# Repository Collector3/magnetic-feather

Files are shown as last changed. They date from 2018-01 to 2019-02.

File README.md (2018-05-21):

# Magnetic Feather Case

Designed for [Adafruit's Feather series](https://learn.adafruit.com/adafruit-feather/overview). 
Flexible enough to use from development to deployment.

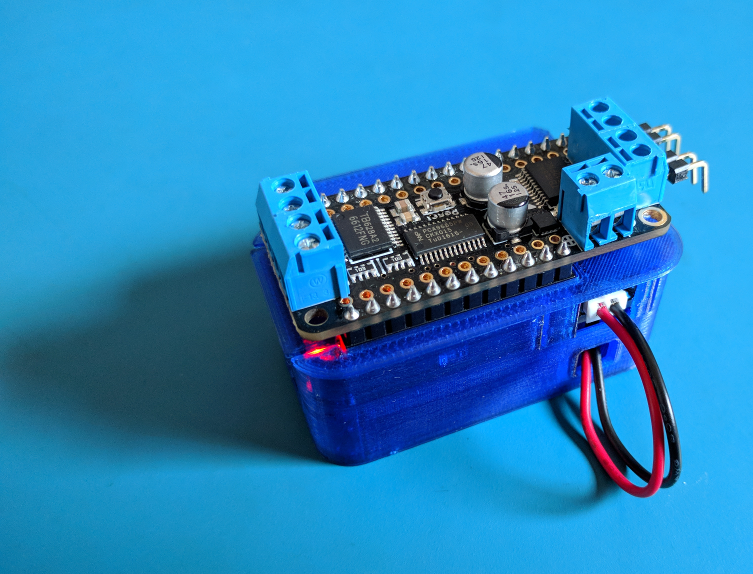
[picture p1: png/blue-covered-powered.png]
Case With Feather Wing Attached


### Features

* Optional compartment for a 350mAh LiPoly battery (with a zip-tie strain relief slot)

* Slot for a rare earth badge magnet (source provided)

* Support for Adafruit's stackable Feather wings

* Cable management and routing slots

* Upside down board support (battery version only)

### Materials Required

#### Feather + Screws

* 1x Adafruit Feather (ESP8266, Bluefruit, ESP32, Adalogger 32u4 were used during prototyping/building)

* 2x M2.5 x 6mm socket head cap screws (source: [Trimcraft Aviation RC](https://www.trimcraftaviationrc.com/index.php?route=product/product&product_id=182))

#### Battery (optional)

* 1x Lithium Ion Polymer Battery - 3.7v 350mAh 552035 - [PKCell 552035, Adafruit](https://www.adafruit.com/product/2750). There are shipping restrictions on lithium polymer batteries, so a local source with the same model/dimensions might be more suitable.

#### Magnet

* 1x Badge Magnet - [Amazon 10-pack](https://www.amazon.com/totalElement-Magnetic-Fastener-Adhesive-10-Pack/dp/B00EHK287M) -- the one [sold by Adafruit is tested as well](https://www.adafruit.com/product/1170)

### Printing

Print these parts:

* 1x - Case (choose between the battery and non-battery version)

* 1x - Cover (choose between the JST access and more enclosed version)

* 1x - Magnet retainer

* 1x - Reset button

* 2x - M2.5 plastic spacers

### Assembly

#### Battery

After printing all three parts, place the battery in first. The battery wiring can be routed through the front of the case, and looped up the side to the Feather's JST header. If desired, add a small zip tie (for a bit of strain relief) on the front of the case.

For the visually inclined, photos are provided below.

#### Badge magnet and retainer

The badge magnet goes into the case with the warning symbols facing up. 

For magnets with a metal-only plate: Insert the magnet retainer with the 1st printed layer facing upward. 

For magnets with a plastic backing: Flip the magnet retainer over so that the last printed layer faces upwards.

Press the retainer through the clips. The retainer should click in and press against the magnet. If there is space between the retainer and magnet, the retainer might need to be flipped over.

#### Feather PCB

Finally, add the Feather PCB into the case, ensuring the board seats into the case's rear notches fully. Carefully press the board down in front. 

Attach a printed spacer to a screw by screwing it on.

Finally, attach the screw to the Feather PCB. The LEDs will be in close proximity to the screw heads, but should not interfere.

#### Reset Button

Attach the button to the lid. It requires a bit of force, so the best way may be to either shave off a bit of filament on the button with a file, or to press it in by tapping the cover onto the button.

### Photos

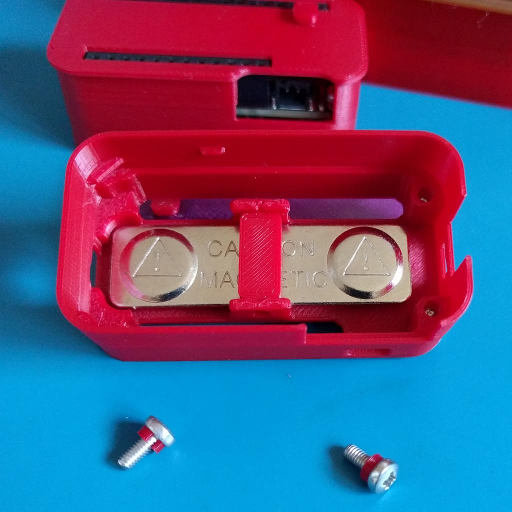
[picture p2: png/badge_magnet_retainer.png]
Badge magnet with printed retainer


The badge magnet is held in by a printed retainer. It is quite strong (this particular one has survived a few hard drops), and should be easy to insert after the badge magnet has been seated in the case. Be sure that it clicks into place fully and that there is little to no movement of the magnet.

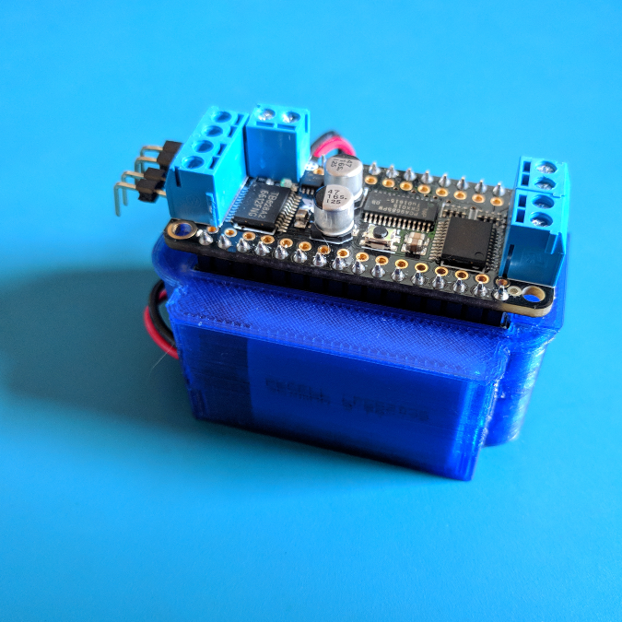
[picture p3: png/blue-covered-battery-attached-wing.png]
Attached Feather Wing with battery


Assembled case with a Feather and Feather wing attached. The battery wiring is routed through the case, past a point where a small zip tie can be used to fix the wires in place.

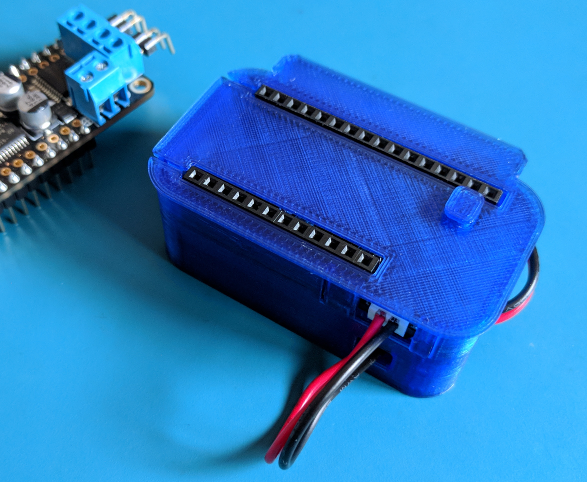
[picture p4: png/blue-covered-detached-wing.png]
Detached Wing


After exiting the bottom of the case, the wiring can be routed back up into the JST header. The slot for the JST connector is spaced (with the cover off) for access with two fingers. With a Wing attached, access is a bit more restricted. For now, the cover (and any attached wings), will need to be removed for access to the JST plug.

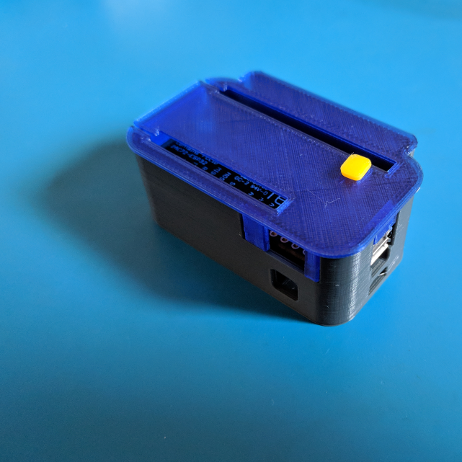
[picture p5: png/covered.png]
Upside down ESP32 Feather


Depending on the Feather/PCB, it may be possible to use a Feather "upside down" for prototyping -- Feathers have different layouts and construction, so inspect the case and Feather's tolerances before trying.

There is no cover for this configuration -- the JST jack is also obstructed.

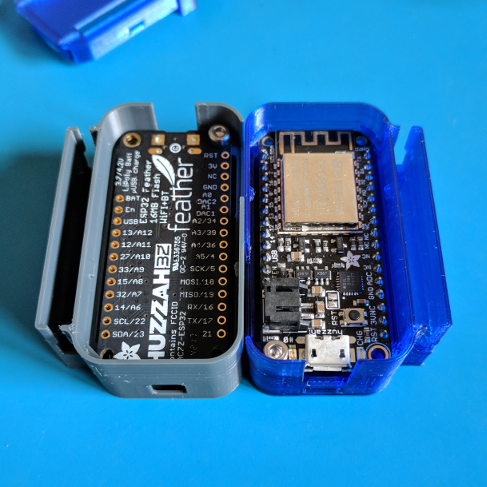
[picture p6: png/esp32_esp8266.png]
ESP32 upside down + ESP8266 side by side


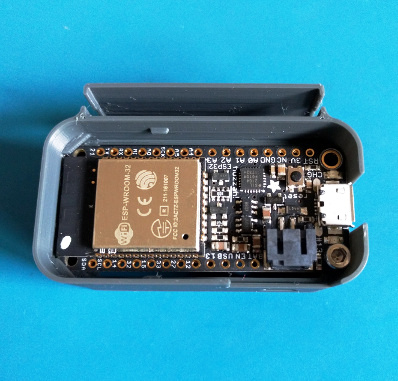
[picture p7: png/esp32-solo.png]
ESP32 without a cover on and one screw


In most configurations, only one hex screw is needed. If the head of the screw gets in the way, try printing the ***M2.5 plastic spacer***, which should provide enough clearance to avoid the LEDs and cover closure.

### Using the Enable Pin To Disconnect Power

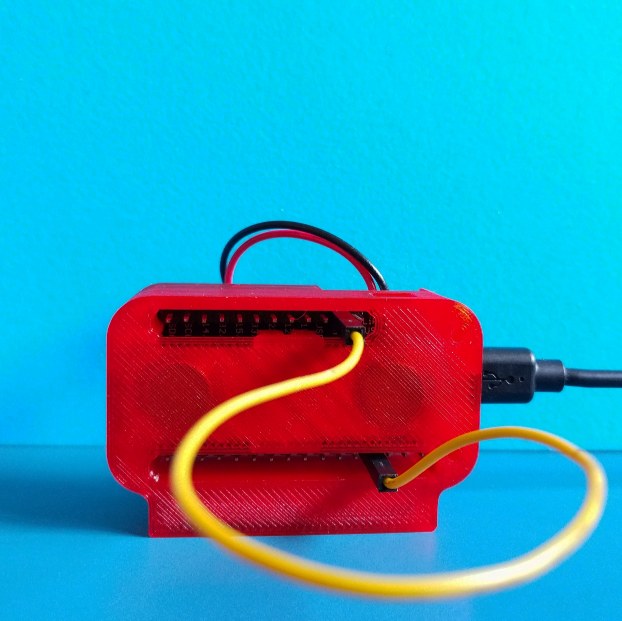
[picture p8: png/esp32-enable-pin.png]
ESP32 Enable Pin Photo


On the ESP32: Nominal consumption with the default program (which scans for SSIDs) is around 130mA (burst). With the enable pin pulled low, quiescent power consumption is around 100μA.

With a full battery, using the enable pin to limit consumption drains a 350 mAh battery in about 100 days (optimistic estimate with an adjustment factor of 0.7).

### Fin

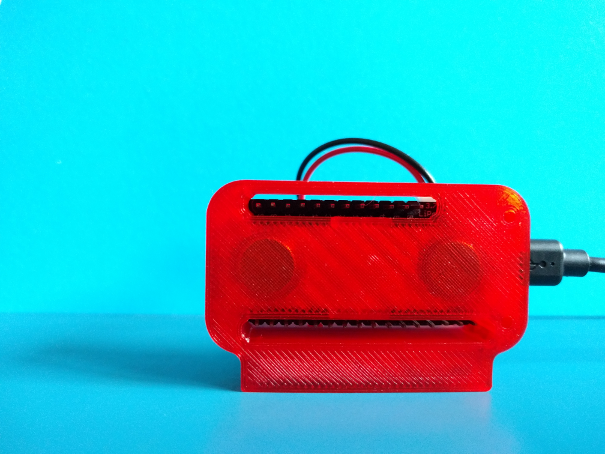
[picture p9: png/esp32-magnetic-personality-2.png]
Final image


More resources:

* [Adafruit's ESP32 Documentation](https://learn.adafruit.com/adafruit-huzzah32-esp32-feather/overview)

* [Adafruit's ESP8266 Documentation](https://learn.adafruit.com/adafruit-feather-huzzah-esp8266/)

* [Adafruit's Feather Series](https://www.adafruit.com/feather/)

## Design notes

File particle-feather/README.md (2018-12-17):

# Particle Feather

A derivitave of the magnetic feather series of cases for the Particle Argon / Xenon (and possibly Boron).

Elsewhere, [Thingiverse](https://www.thingiverse.com/thing:3292215)

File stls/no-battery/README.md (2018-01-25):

# magnetic feather (no battery compartment)

This is a magnetic case with the battery compartment removed. The reset button and magnet retainer are shared with the other parts (look for them in stl/).

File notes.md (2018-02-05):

# Notes

This project is located in other places too.

* [Thingiverse: https://www.thingiverse.com/thing:2749893](https://www.thingiverse.com/thing:2749893)

* [YouMagine: https://www.youmagine.com/designs/magnetic-feather-case](https://www.youmagine.com/designs/magnetic-feather-case)

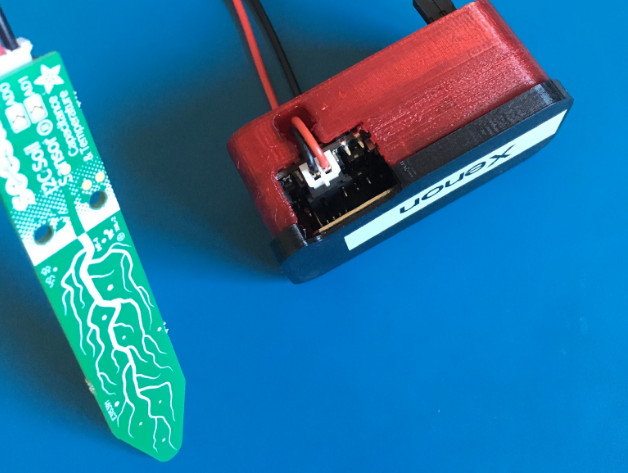
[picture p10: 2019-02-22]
particle-feather/png/feather-ideal-battery-side.png

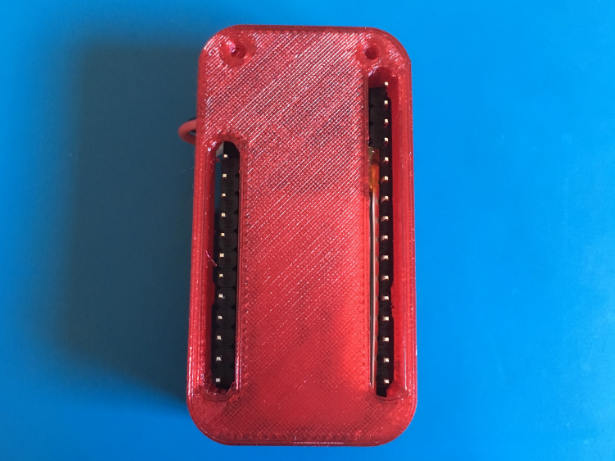
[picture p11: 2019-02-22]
particle-feather/png/feather-ideal-battery-bottom.png

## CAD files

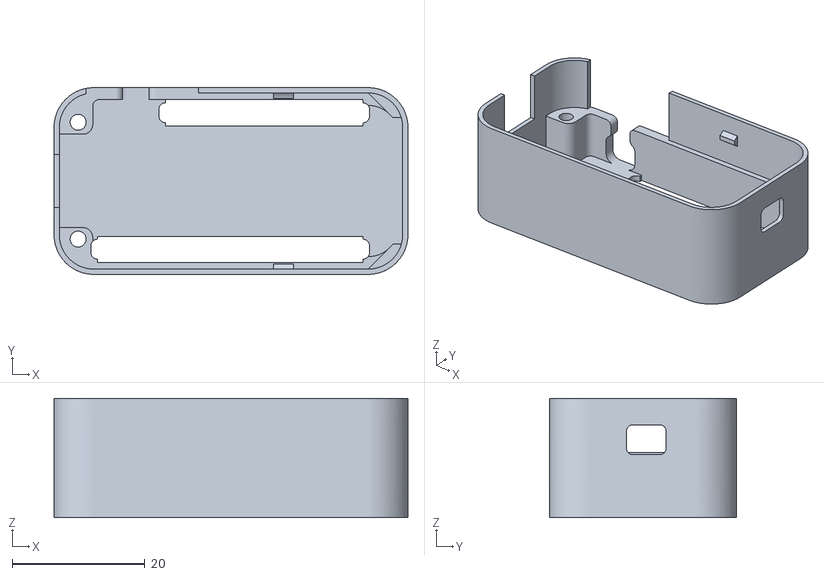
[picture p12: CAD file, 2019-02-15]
particle-feather/Particle-Feather-Ideal-Battery.stl
53.4 x 28.1 x 18.0

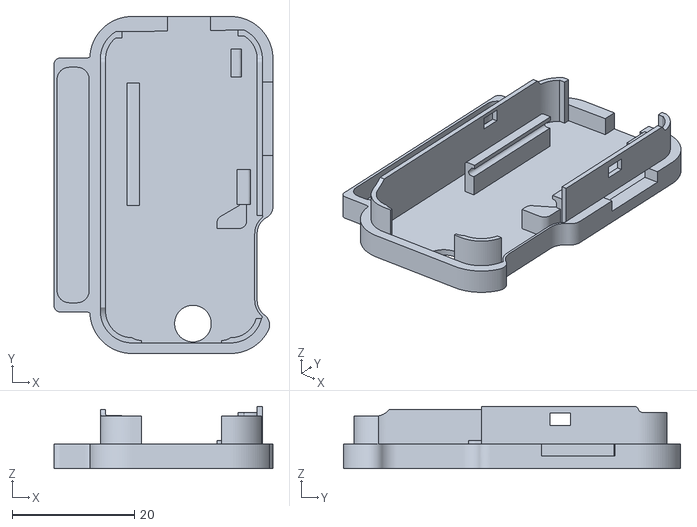
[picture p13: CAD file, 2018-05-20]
stls/camera-module/integrated-cover-camera.stl
35.9 x 55.2 x 10.2

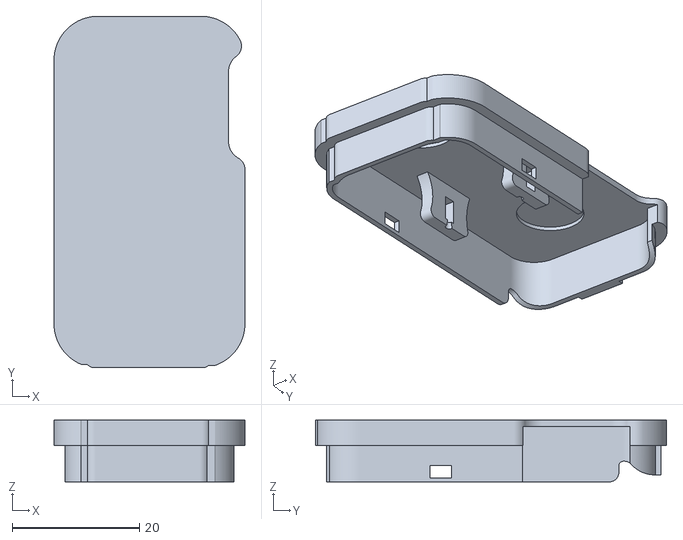
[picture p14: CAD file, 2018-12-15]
stls/feather-magnetic-cover - part.stl
30.0 x 55.2 x 9.70

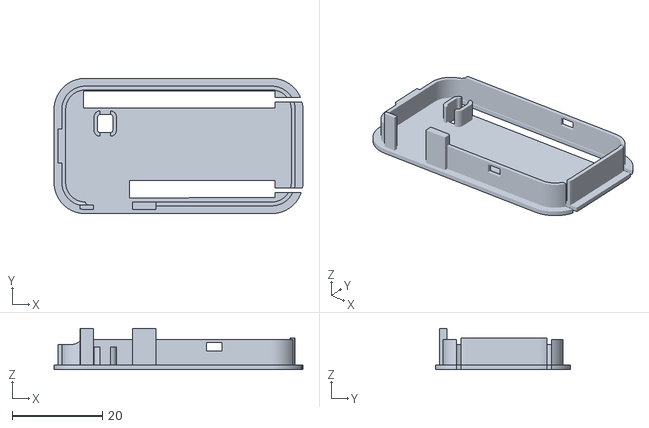
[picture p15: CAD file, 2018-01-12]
stls/no-battery/cover-no-battery.stl
55.2 x 30.0 x 9.20

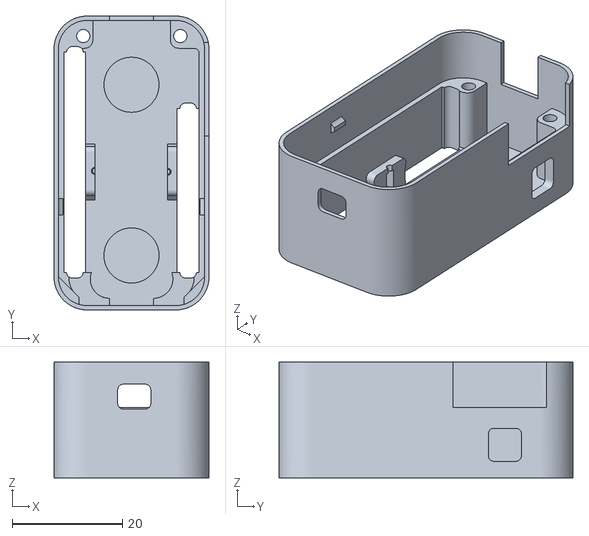
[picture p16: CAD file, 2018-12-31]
particle-feather/Particle-Feather-Base.stl
28.1 x 53.4 x 21.0

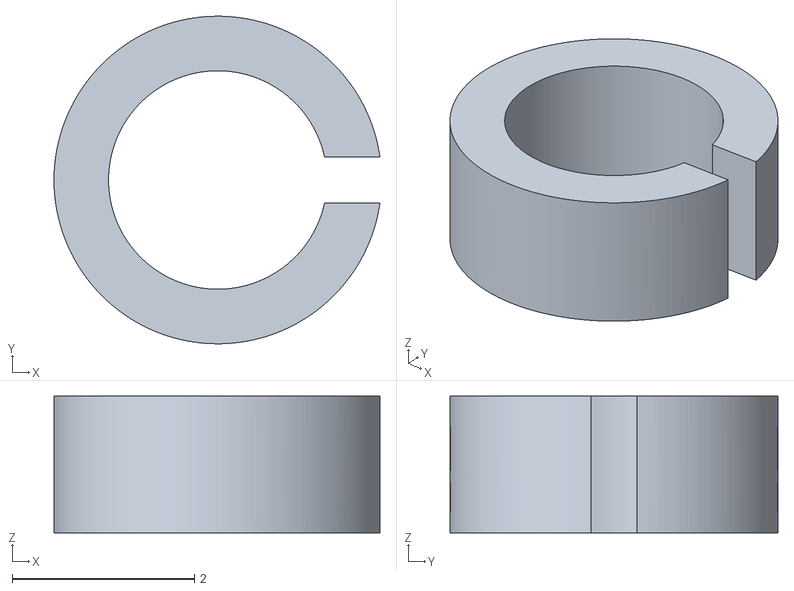
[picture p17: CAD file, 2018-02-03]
stls/feather-m2.5-plastic-spacer.stl
3.58 x 3.60 x 1.50

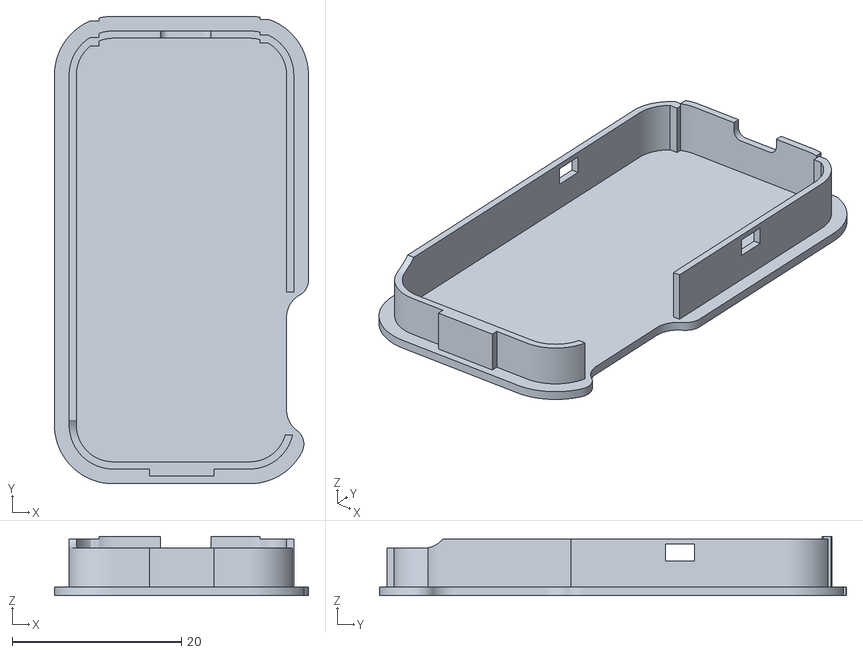
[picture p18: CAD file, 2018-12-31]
particle-feather/Particle-Feather-Top.stl
30.0 x 55.2 x 7.00

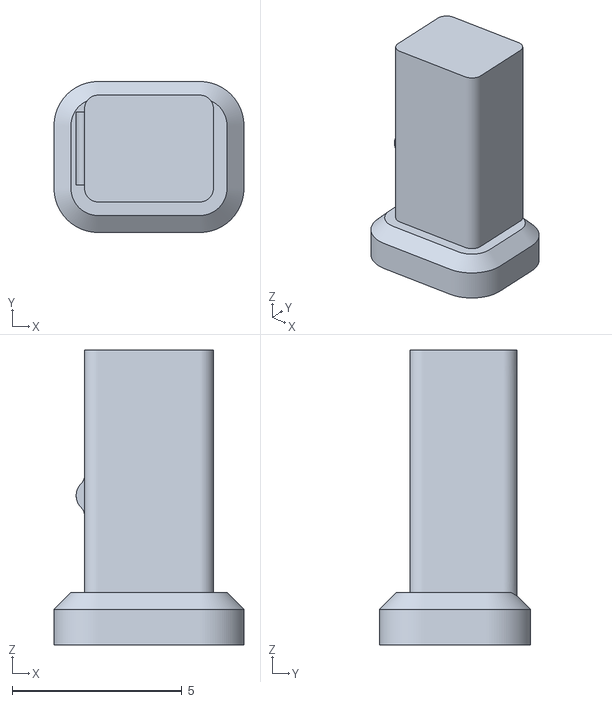
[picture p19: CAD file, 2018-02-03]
stls/reset_button.stl
5.60 x 4.45 x 8.70

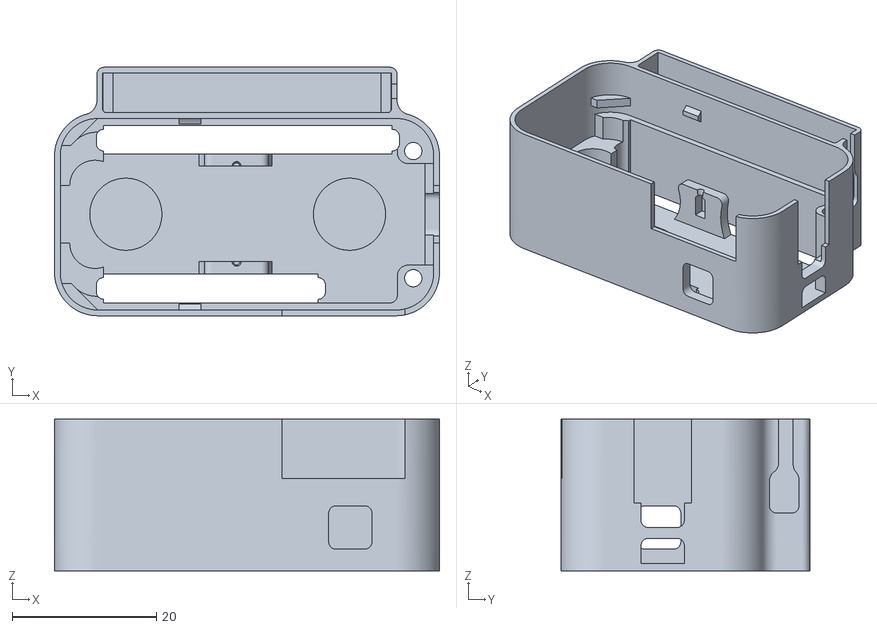
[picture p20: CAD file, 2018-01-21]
stls/case.stl
53.4 x 34.4 x 21.0

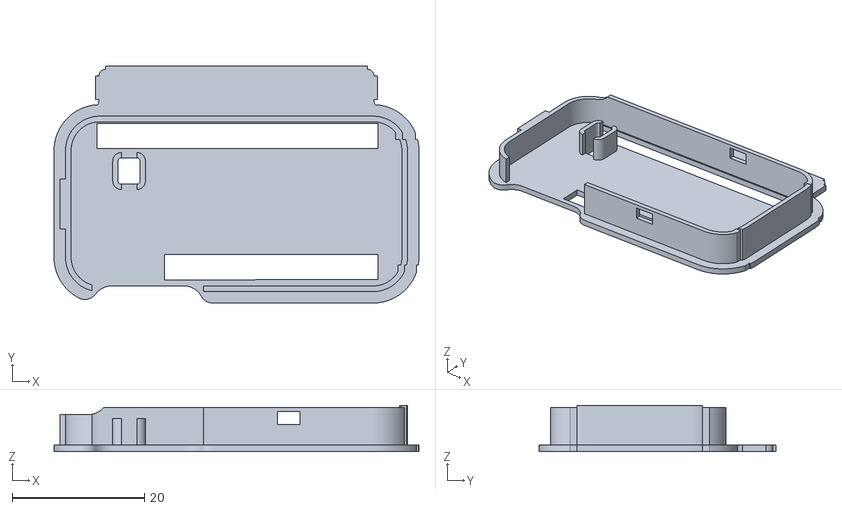
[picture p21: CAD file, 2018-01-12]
stls/cover-jst-access.stl
55.2 x 35.9 x 7.00

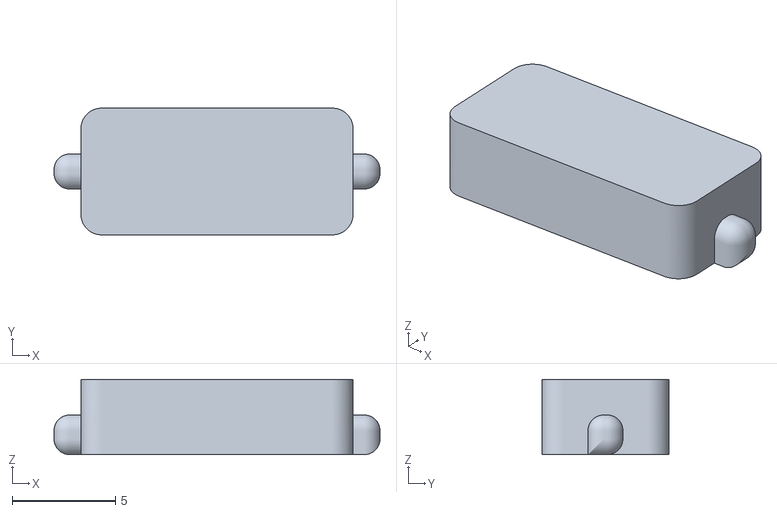
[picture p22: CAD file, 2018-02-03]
particle-feather/magnet-retainer.stl
15.8 x 6.13 x 3.63

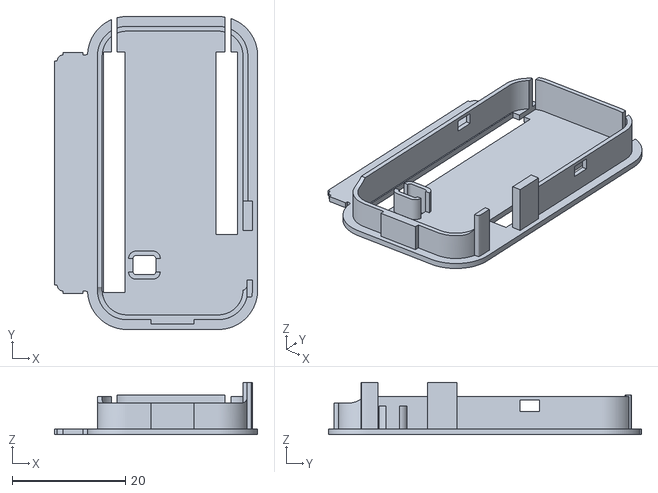
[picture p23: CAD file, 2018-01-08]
stls/cover.stl
35.9 x 55.2 x 9.20

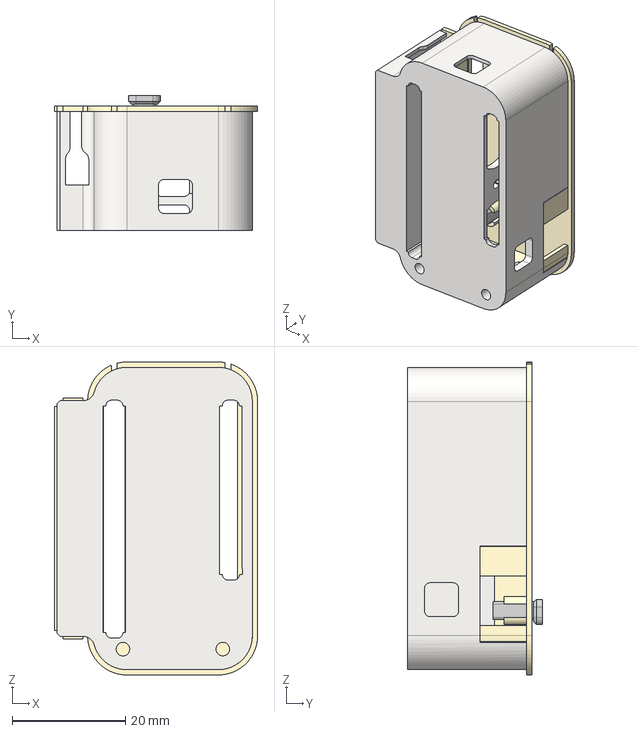
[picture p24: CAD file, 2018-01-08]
stls/esp.stp
35.9 x 23.8 x 55.2 mm

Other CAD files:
particle-feather/Particle-Feather-Top-Magnet.stl
particle-feather/cover-magnet-support.step

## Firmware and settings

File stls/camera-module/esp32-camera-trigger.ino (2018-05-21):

// Sample code for an ESP32 board combined with this camera from Adafruit https://www.adafruit.com/product/3202
//
// This code was cut together (and down) from a combination of:
// RepeatTimer: https://raw.githubusercontent.com/espressif/arduino-esp32/master/libraries/ESP32/examples/Timer/RepeatTimer/RepeatTimer.ino
//  License: Public domain
// CaptivePortal: https://raw.githubusercontent.com/espressif/arduino-esp32/master/libraries/DNSServer/examples/CaptivePortal/CaptivePortal.ino
//  License: LGPL Arduino Port (documentation)
// SimpleWebServer: https://raw.githubusercontent.com/espressif/arduino-esp32/master/libraries/WiFi/examples/SimpleWiFiServer/SimpleWiFiServer.ino
//  License: LGPL Arduino Port (documentation)
// Any other unique bits should also be considered as: LGPL licensed
//
#include <WiFi.h>
#include <DNSServer.h>

#define TRIG_PIN A0
#define BATTERY_V_PIN A13

DNSServer dnsServer;
WiFiServer server(80);

const byte DNS_PORT = 53;
const int timelapseIntervalSeconds = 5;

IPAddress apIpAddr(192, 168, 4, 1);
bool timelapse = false;

const char* ssid     = "CAMERA-CONTROLLER";
const char* password = "";

hw_timer_t * timer = NULL;
volatile SemaphoreHandle_t timerSemaphore;
portMUX_TYPE timerMux = portMUX_INITIALIZER_UNLOCKED;

void IRAM_ATTR onTimer(){
  xSemaphoreGiveFromISR(timerSemaphore, NULL);
  takePhoto();
}

void setup()
{
    Serial.begin(115200);
    
    pinMode(TRIG_PIN, OUTPUT);
    digitalWrite(TRIG_PIN, HIGH);
        
    pinMode(BATTERY_V_PIN, INPUT);
    
    WiFi.mode(WIFI_AP);
    WiFi.softAPConfig(apIpAddr, apIpAddr, IPAddress(255, 255, 255, 0));
    WiFi.softAP(ssid, password);
    
    Serial.println(ssid);
    Serial.println(password);
        
    dnsServer.start(DNS_PORT, "*", apIpAddr);
    server.begin();
    
    timerSemaphore = xSemaphoreCreateBinary();
    timer = timerBegin(0, 80, true);
    timerAttachInterrupt(timer, &onTimer, true);

    timerAlarmWrite(timer, timelapseIntervalSeconds * 1000000, true);
    Serial.println("Entering main loop()");
}

// takePhoto() snaps a picture
// Line is assumed to be HIGH before calling this
void takePhoto() {        
    digitalWrite(TRIG_PIN, LOW);
    delay(50);
    Serial.println("Photo taken.");
}

// takeVideo() toggles video recording
// Line is assumed to be HIGH before calling this
void takeVideo() {
    digitalWrite(TRIG_PIN, LOW);
    delay(800);
    Serial.println("Toggled video recording."); 
}

// getBatteryVoltage() returns the internal battery voltage
// measured by a /2 resistive divider on pin A13 (specific
// to the ESP32 HUZZAH)
float getBatteryVoltage() {
    return (analogRead(BATTERY_V_PIN) * 2);
}

void loop() {
  dnsServer.processNextRequest();
  WiFiClient client = server.available();

  digitalWrite(TRIG_PIN, HIGH);

  if (client) {                             
    Serial.println("Incoming connection.");
    String currentLine = "";
    while (client.connected()) {
      if (client.available()) {
        char c = client.read();
        Serial.write(c);
        if (c == '\n') {
          if (currentLine.length() == 0) {
            client.println("HTTP/1.1 200 OK");
            client.println("Content-type:text/html");
            client.println();

            client.print("My IP is: ");
            client.print("<a href=\"");
            client.print("\"");
            client.print(apIpAddr);
            client.print("/");
            client.print(">");
            client.print(apIpAddr);
            client.print("</a><br><br><br>");
            
            client.print("Battery voltage is: ");
            client.print(getBatteryVoltage());
            client.print(" mV");
            client.print("<br><br><br>");
            client.print("<a href=\"/PHOTO\">TAKE A PHOTO</a><br><br><br>");
            client.print("<a href=\"/VIDEO\">START/STOP VIDEO</a><br><br><br>");
            
            if(timelapse) {
              client.print("Photo timelapse: Started<br><br>");
            } else {
              client.print("Photo timelapse: Stopped<br><br>");
            }
            
            client.print("<a href=\"/TIMELAPSE\">START/STOP PHOTO TIMELAPSE</a><br><br><br>");
                               
            client.println();
            break;
            
          } else {
            currentLine = "";
          }
        } else if (c != '\r') {
          currentLine += c;
        }

        if (currentLine.endsWith("GET /TIMELAPSE")) {
          
          if (!timelapse) {
            
            timelapse = true;
            timerAlarmEnable(timer);
            Serial.print("Timelapse mode enabled");
            
          } else {
            
            timelapse = false;
            
            if (timer) {
              timerEnd(timer);
            }
            
            Serial.print("Timelapse mode disabled");
            
          }
        }
        
        if (currentLine.endsWith("GET /PHOTO")) {
          takePhoto();
        }
        
        if (currentLine.endsWith("GET /VIDEO")) {
          takeVideo();
        }
        
      }
    }
    
    client.stop();
    Serial.println("Connection finished.");
    
  }
}

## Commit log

2018-01-03 case -> board
2018-01-03 More about the enable pin
2018-01-08 Enable pin corrections
2018-01-08 Add license for project
    [case.stl, cover.stl, esp.stp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]
2018-01-08 Rotate all STLs for printability
    [case.stl, cover.stl, reset_button.stl]
2018-01-10 Add a printed part for fixing the magnet in place
    [feather-case-magnet-fixer.stl]
2018-01-10 Move feather-case-magnet-fixer.stl to stls directory
    [feather-case-magnet-fixer.stl]
2018-01-12 Add new magnet retainer and case
    This changes out the filament based fixing system for a snap-in magnet
    retainer that works with both plastic backed magnets and metal-only
    backed badge magnets
    [case.stl, feather-case-magnet-fixer.stl, magnet-retainer.stl]
2018-01-12 Add case with no battery compartment
    This retains the reset button and magnet holder but deletes the battery
    compartment for users who wish to save on a bit of space
    [case-no-battery.stl, cover-no-battery.stl]
2018-01-12 Battery case printability
    This removes the slight chamfer and exchanges it with a fillet matching
    the lid
    [case.stl]
2018-01-12 Flip for printability
    [cover-no-battery.stl]
2018-01-12 Testing: Add a cover with JST access
    [cover-jst-access.stl]
2018-01-12 Testing: Add a no battery cover w/o JST access
    [cover-no-battery-jst-access.stl]
2018-01-18 A magnet retainer with easier insertion
    [easier-magnet-retainer.stl]
2018-01-18 Mirroring fillets
    [easier-magnet-retainer.stl]
2018-01-20 Testing: A more compact case (no battery compartment)
    [feather-no-battery-compressed.stl]
2018-01-20 Testing: Compressed version magnet retainer changes
    Attempt to make the magnetic retainer even easier to insert
    [feather-no-battery-compressed.stl]
2018-01-21 Update cases
    This adds/removes the following features:
    Battery case:
    Cutout on the opposite end of the battery compartment (reasoning: this
    makes the compartment more crushproof)
    Non-battery: Adjusted cutouts and closed USB port - non-battery is not
    designed/intended for upside down use
    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
    [case.stl, feather-no-battery-compressed.stl]
2018-01-21 Move testing items into production
    This makes the easier magnet retainer the default, and the sqashed (by
    ~3mm) no battery case the default for no-battery cases
    [case-no-battery.stl, easier-magnet-retainer.stl, feather-no-battery-compressed.stl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]
2018-01-21 Add a better reset button
    This button sits higher than the previous version, allowing the JST
    accessible versions the ability to press it more easily.
    The old button relied on the springiness provided by the two rear cover
    cutouts to function properly
    [reset_button.stl]
2018-01-27 Plastic spacer: Reduce overall diameter
    [feather-m2.5-plastic-spacer.stl]
2018-02-02 Small fix to the BOM and instructions
2018-02-03 (╯°□°）╯ [ sʇuᴉɹd pƐ ] -> [ 3d prints ]
    [case-no-battery.stl, feather-m2.5-plastic-spacer.stl, magnet-retainer.stl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]
2018-02-04 Update README with badge magnet photo
2018-05-20 Add a camera cover for the magnetic-feather series
    This fits Adafruit's http://adafru.it/3202
    [integrated-cover-camera.stl]
2018-12-15 Add a cover that takes a badge magnet
    [feather-magnetic-cover - part.stl]
2018-12-17 Add Particle Feather files
    [case.stl, cover-magnet-support.step, cover-magnet-support.stl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]
2018-12-31 Re-add Particle Feather case files
    [Particle-Feather-Base.stl, Particle-Feather-Top-Magnet.stl, Particle-Feather-Top.stl]
2019-02-15 Particle Feather case for bottom-side batteries
    This fits https://www.adafruit.com/product/3898 and is used with the badge magnet relocated to the lid.
    [Particle-Feather-Ideal-Battery.stl]
2019-02-22 Add new images for the feather-ideal-battery
    This also reflects a publish of this on Thingiverse, here:
    https://www.thingiverse.com/thing:3445605
